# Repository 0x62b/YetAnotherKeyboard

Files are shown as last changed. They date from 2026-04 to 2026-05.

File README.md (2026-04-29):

# YetAnotherKeyboard
This is an 65% mechanical keyboard with hot-swappable MX style switches. The design is based on a nice!nano microcontroller and a nice!view display.
It also supports wireless operation with a standard lithium polymer battery. The nano also supports a USB connection.

## Repo structure
- CAD files including the individual parts and full assembly can be found in `cad/`
- The KiCad PCB design files can be found in `PCB/`
- Production gerbers can be found in `PCB/production`
- Firmware can be found in `firmware/`

## BOM
Total cost: 55.39 USD\
Parts can all be sourced from AliExpress.

## PCB
Parameters:
* 2 layer
* Material: FR-4
* Either HASL (leaded is much cheaper)
* White solder mask

Dimensions: 98.21mm*329.75mm\
PCB cost: 17 USD\
Shipping cost: 12.83 USD\
Total cost: 29.83 USD

## Case
Material: PLA, PETG, anything is fine really\
Nozzle: 0.4mm/0.6mm/0.8mm\
The case is far too big to fit on a standard 256mm^3 bed. If you want to replicate this build (for some reason) you may need to split the case. However I have access to a Prusa XL so I will use that.

## Firmware
ZMK, firmware is located in a submodule, https://github.com/0x62b/YetAnotherKeyboard-config

## Cost
Parts: 55.39 USD\
PCB: 29.83 USD\
Grand total: 85.22 USD (approx because of conversion rates)

## Images


There's probably a more efficient way to do matrix but...




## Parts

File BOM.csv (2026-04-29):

Name | Quantity | Unit price (AUD) | Extended Price (AUD) | Extended Price(USD) | Notes | Link
Pro Micro NRF52840 | 1 | 5.83 | 5.83 | 4.18 | nice!nano footprint is Pro Micro compatible | https://www.aliexpress.com/item/1005007266112508.html
nice!view | 1 | 19.59 | 19.59 | 14.02 | its probably some aliexpress knockoff but if it works it works (and if it doesnt i return it) | https://www.aliexpress.com/item/1005011620429396.html
1N4148 SOD-123 | 66 | 0.0284 | 2.84 | 2.04 | 100 pack | https://www.aliexpress.com/item/1005006323468521.html
0402 1K resistor | 1 | 0 | 0 | 0 | Owned | N/A
SPST push button | 1 | 0.039 | 1.94 | 1.39 | 50 pack | https://www.aliexpress.com/item/1005005279088080.html
MX switches | 66 | 0.42 | 29.39 | 21.10 | 70 pack | https://www.aliexpress.com/item/1005007983672026.html
Keycaps set | 1 | 0 | 0 | 0 | Owned | https://www.aliexpress.com/item/1005009162201589.html
Stabilisers | 1 | 3.99 | 3.99 | 2.86 | N/A | https://www.aliexpress.com/item/1005007212869086.html
Battery | 1 | 0 | 0 | 0 | Owned | https://core-electronics.com.au/lipo-polymer-lithium-ion-battery-120mah.html
Hotswap sockets | 1 | 12.29 | 12.29 | 8.8 | 100 pack | https://www.aliexpress.com/item/1005006105603269.html

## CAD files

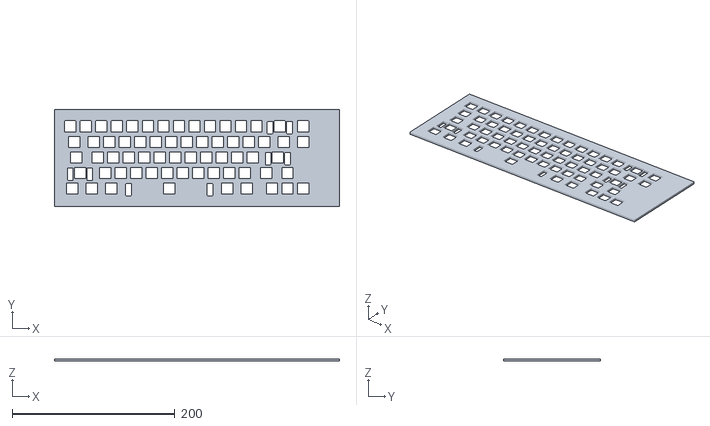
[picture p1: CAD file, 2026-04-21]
cad/top case.stl
350.1 x 118.6 x 3.00

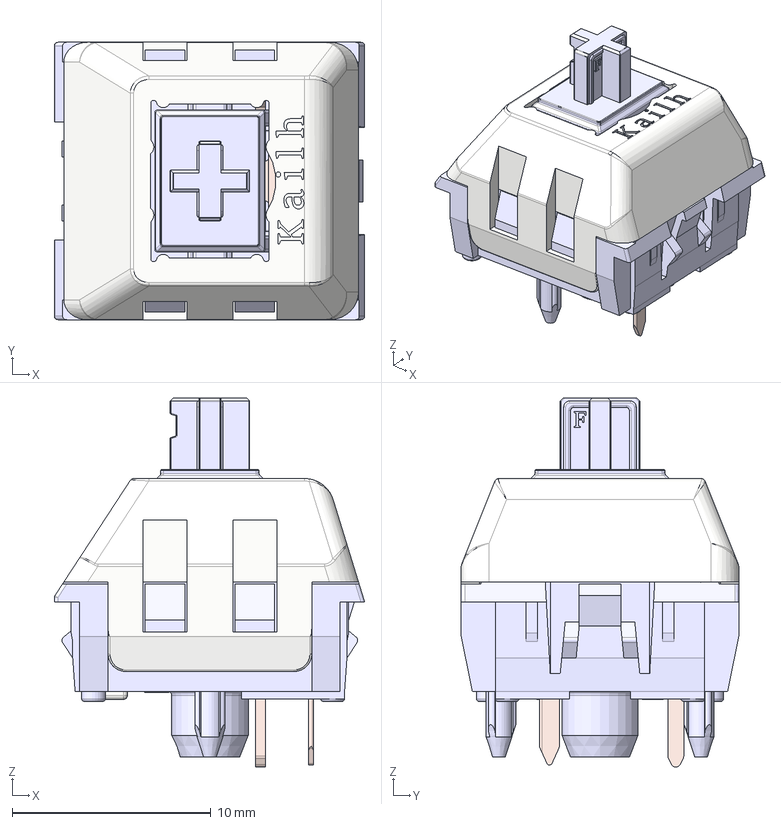
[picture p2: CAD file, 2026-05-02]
PCB/models/Kailh Polia.step
15.6 x 14.0 x 18.5 mm
Housing
ThickContact
SpringContact
Stem
Lid

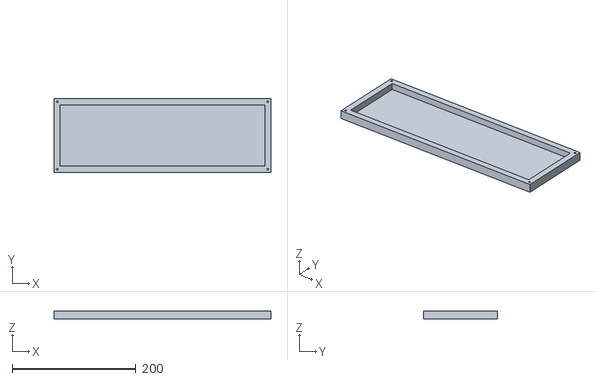
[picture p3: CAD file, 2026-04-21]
cad/bottom case.stl
350.1 x 118.6 x 13.0

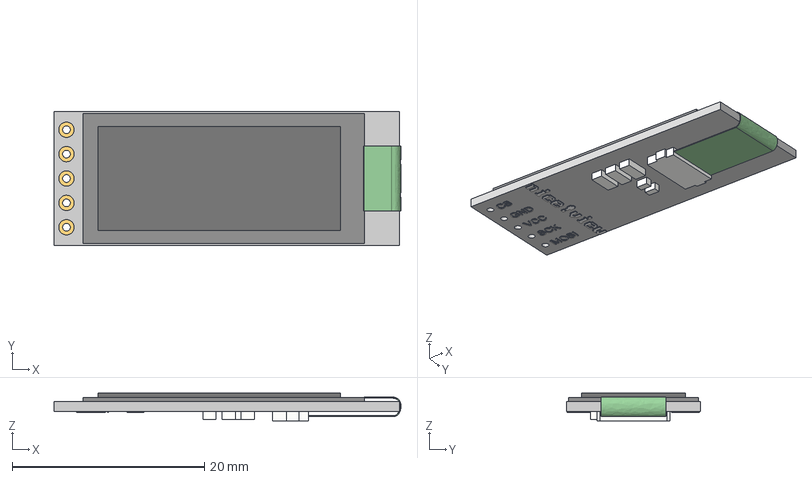
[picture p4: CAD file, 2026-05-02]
PCB/models/nice!view.step
36.1 x 14.0 x 2.90 mm

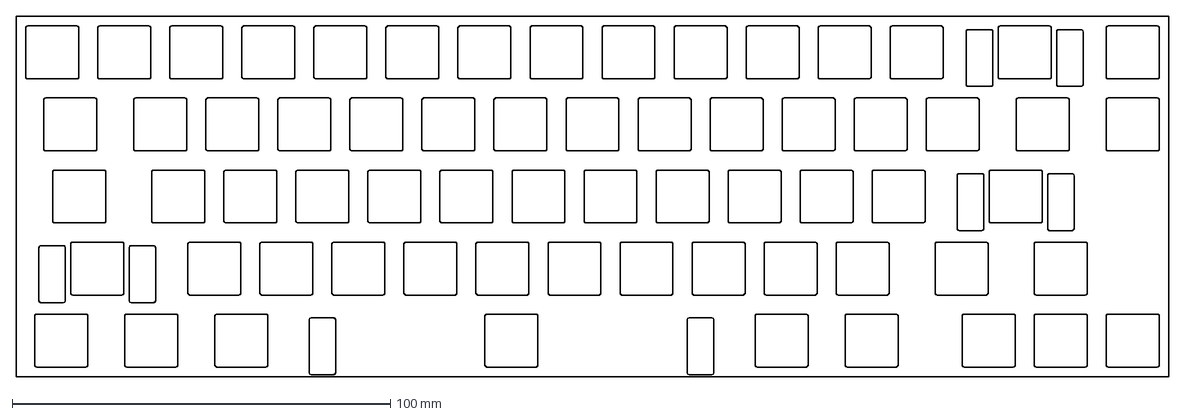
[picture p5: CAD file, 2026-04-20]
cad/plate-2026-04-20T23_23_47.740Z.dxf
304.8 x 95.2 mm

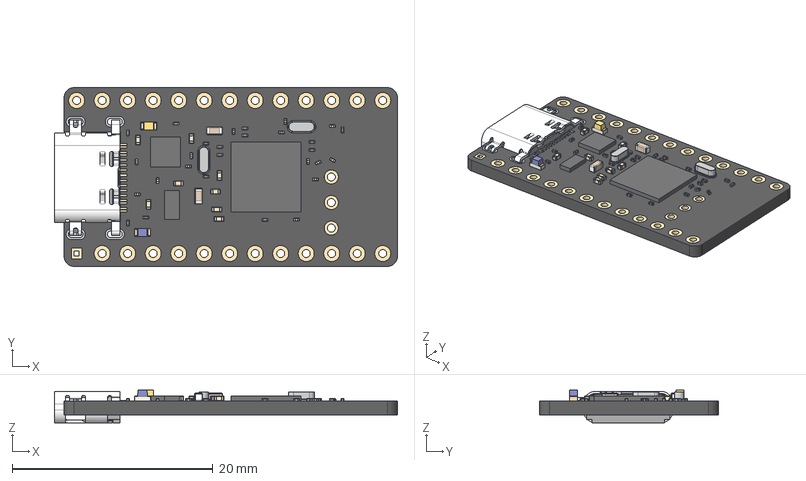
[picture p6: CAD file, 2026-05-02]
PCB/models/nice!nano v2.step
34.2 x 17.8 x 3.28 mm
nice!nano v1.0
SSOP16
LED_0603_1608Metric_ON
LED_0603_1608Metric_ON_1
Crystal Oscillator
Crystal Oscillator_1
usb4520-03-0-a_1
C0201 x 21
C0402 x 8
C0201_1 x 7

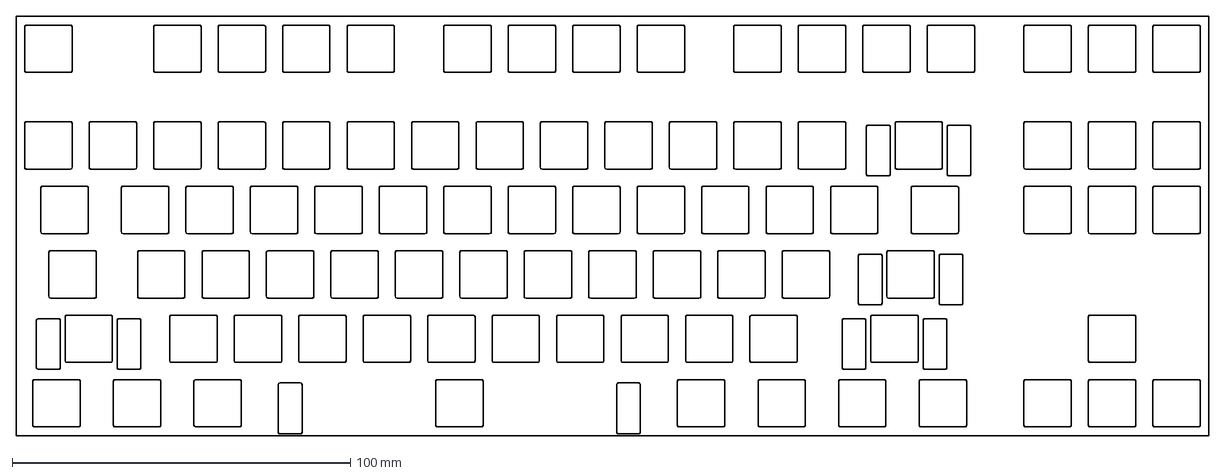
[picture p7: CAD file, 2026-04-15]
cad/plate-2026-04-14T12_41_01.630Z.dxf
352.4 x 123.8 mm

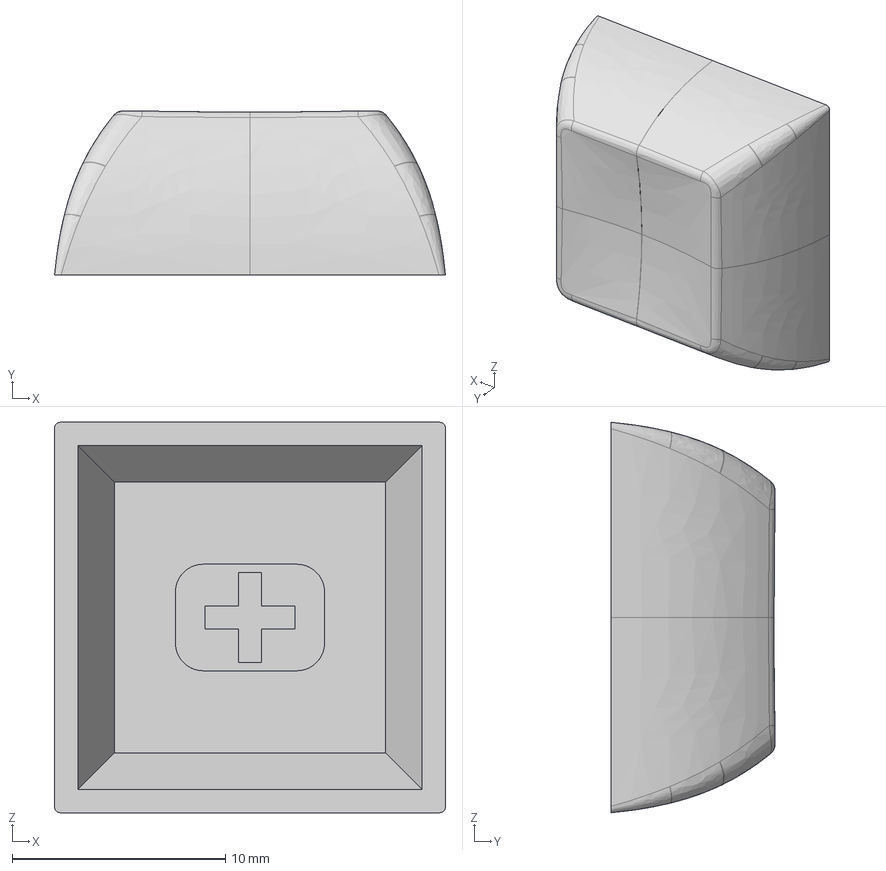
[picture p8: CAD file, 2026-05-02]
PCB/models/DSA_Keycap_CherryMX.step
18.3 x 7.69 x 18.3 mm

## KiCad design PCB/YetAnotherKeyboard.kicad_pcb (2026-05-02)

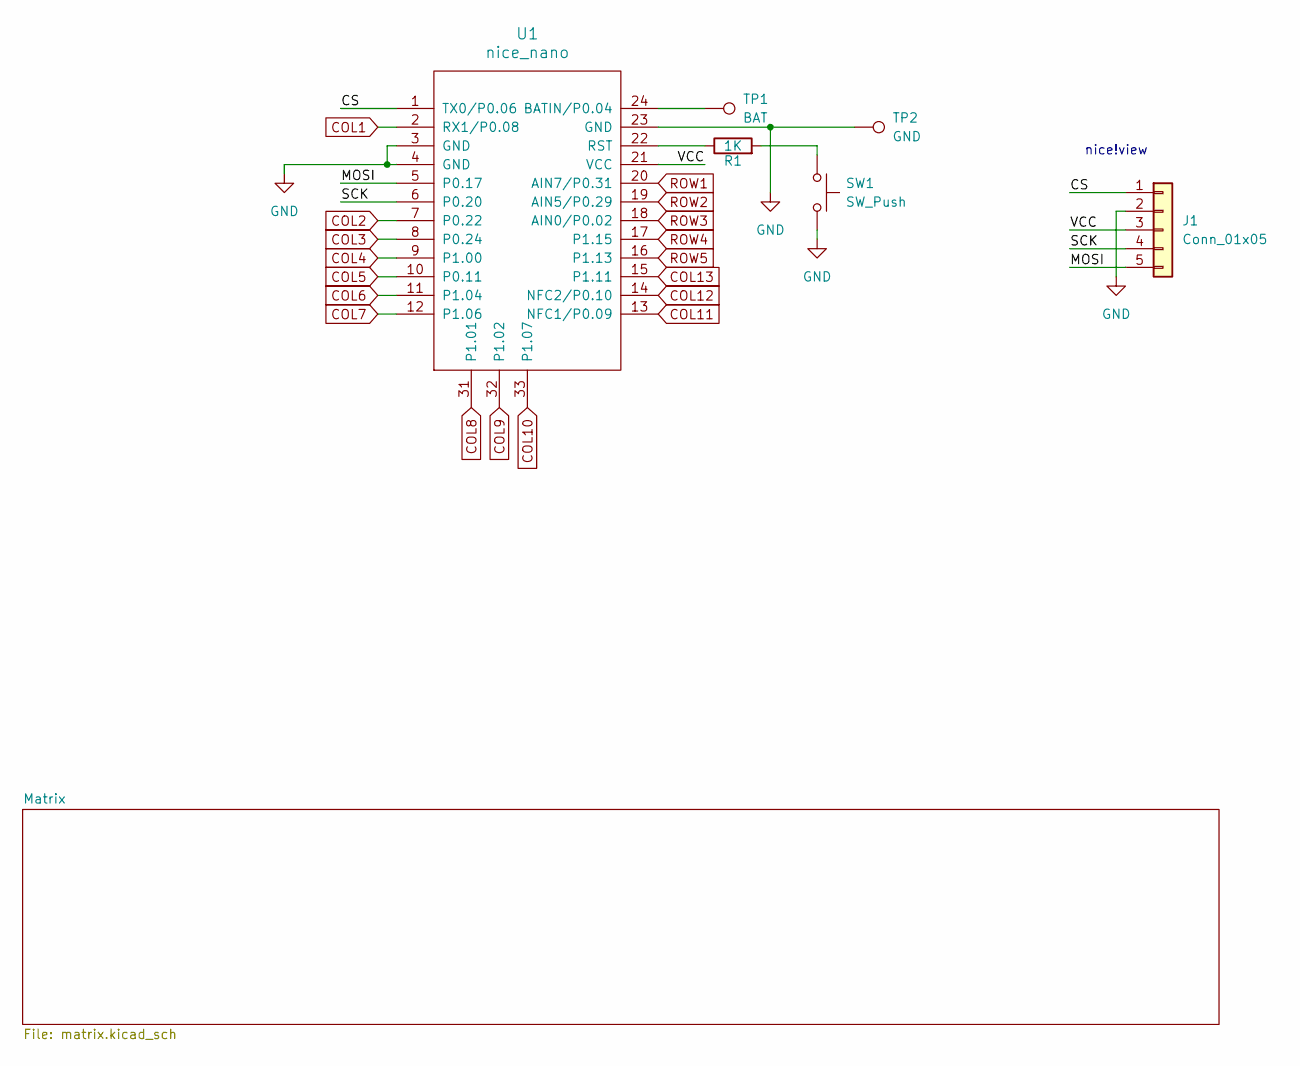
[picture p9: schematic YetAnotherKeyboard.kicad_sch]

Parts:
J1: Conn_01x05; PinHeader_1x05_P2.54mm_Vertical
R1: 1K; R_0402_1005Metric
SW1: SW_Push; SW_Push_SPST_NO_Alps_SKRK
TP1: BAT; TestPoint_Pad_D2.0mm
TP2: GND; TestPoint_Pad_D2.0mm
U1: nice_nano

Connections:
/CS: J1.1, U1.1 (TX0/P0.06)
/MOSI: J1.5, U1.5 (P0.17)
/SCK: J1.4, U1.6 (P0.20)
/VCC: J1.3, U1.21 (VCC)
COL1: U1.2 (RX1/P0.08); also elsewhere on the board
COL2: U1.7 (P0.22); also elsewhere on the board
COL3: U1.8 (P0.24); also elsewhere on the board
COL4: U1.9 (P1.00); also elsewhere on the board
COL5: U1.10 (P0.11); also elsewhere on the board
COL6: U1.11 (P1.04); also elsewhere on the board
COL7: U1.12 (P1.06); also elsewhere on the board
COL8: U1.31 (P1.01); also elsewhere on the board
COL9: U1.32 (P1.02); also elsewhere on the board
COL10: U1.33 (P1.07); also elsewhere on the board
COL11: U1.13 (NFC1/P0.09); also elsewhere on the board
COL12: U1.14 (NFC2/P0.10); also elsewhere on the board
COL13: U1.15 (P1.11); also elsewhere on the board
GND: J1.2, SW1.2, TP2.1 (1_1), U1.3 (GND), U1.4 (GND), U1.23 (GND)
unnamed: R1.2, SW1.1
unnamed: TP1.1 (1_1), U1.24 (BATIN/P0.04)
unnamed: R1.1, U1.22 (RST)
ROW1: U1.20 (AIN7/P0.31); also elsewhere on the board
ROW2: U1.19 (AIN5/P0.29); also elsewhere on the board
ROW3: U1.18 (AIN0/P0.02); also elsewhere on the board
ROW4: U1.17 (P1.15); also elsewhere on the board
ROW5: U1.16 (P1.13); also elsewhere on the board

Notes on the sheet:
nice!view

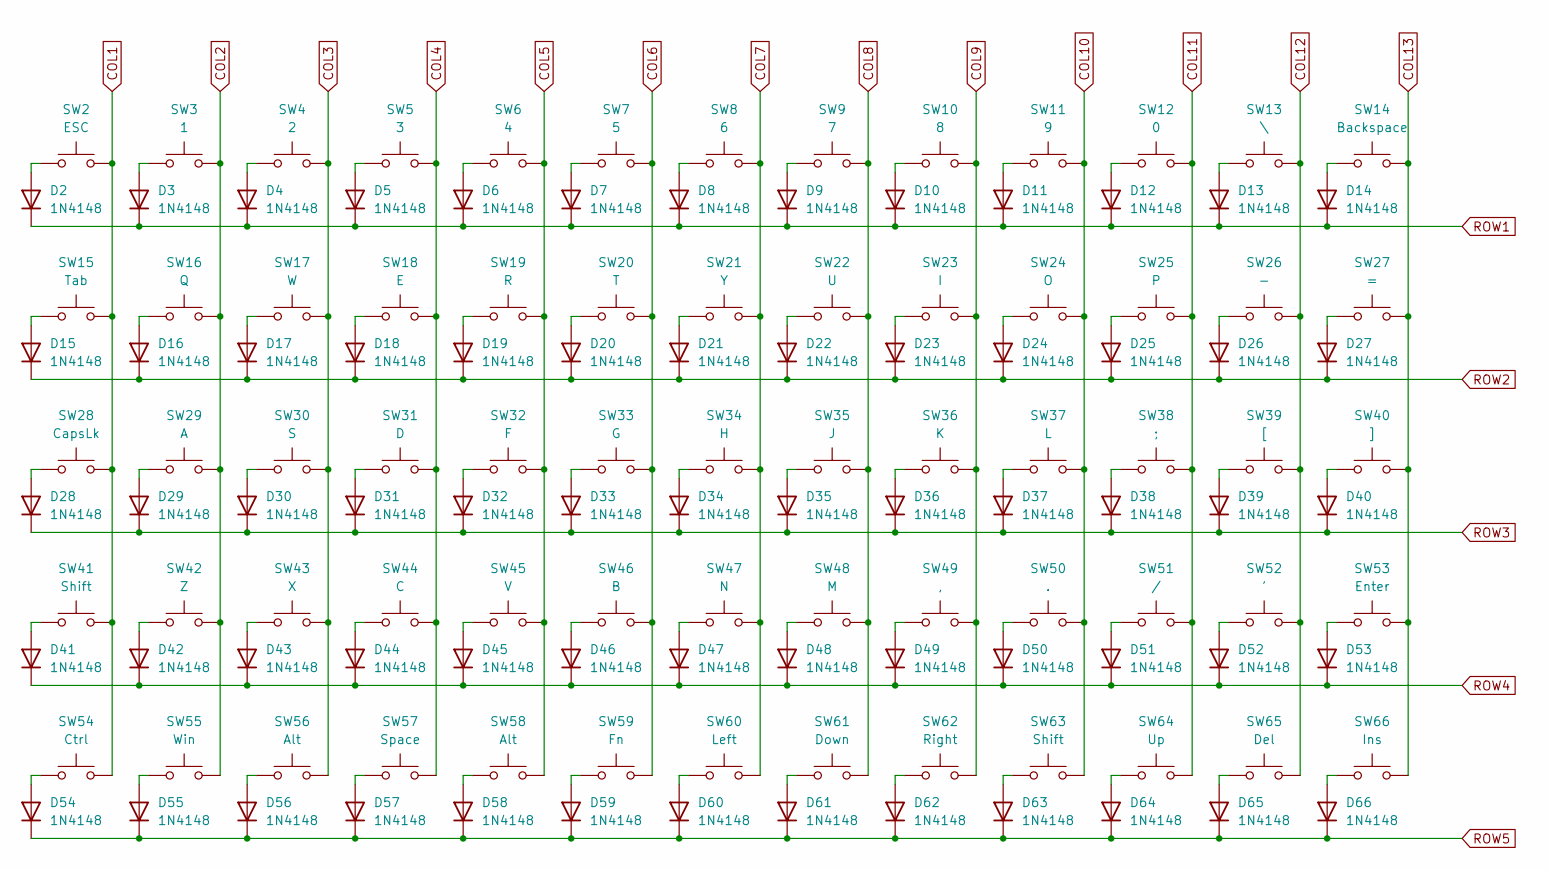
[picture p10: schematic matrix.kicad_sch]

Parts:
D2, D3, D4, D5, D6, D7, D8, D9, D10, D11, D12, D13, D14, D15, D16, D17, D18, D19, D20, D21, D22, D23, D24, D25, D26, D27, D28, D29, D30, D31, D32, D33, D34, D35, D36, D37, D38, D39, D40, D41, D42, D43, D44, D45, D46, D47, D48, D49, D50, D51, D52, D53, D54, D55, D56, D57, D58, D59, D60, D61, D62, D63, D64, D65, D66: 1N4148; D_SOD-123
SW2: ESC; MX-Hotswap-1U
SW3: 1; MX-Hotswap-1U
SW4: 2; MX-Hotswap-1U
SW5: 3; MX-Hotswap-1U
SW6: 4; MX-Hotswap-1U
SW7: 5; MX-Hotswap-1U
SW8: 6; MX-Hotswap-1U
SW9: 7; MX-Hotswap-1U
SW10: 8; MX-Hotswap-1U
SW11: 9; MX-Hotswap-1U
SW12: 0; MX-Hotswap-1U
SW13: \; MX-Hotswap-1.5U
SW14: Backspace; MX-Hotswap-2U
SW15: Tab; MX-Hotswap-1.5U
SW16: Q; MX-Hotswap-1U
SW17: W; MX-Hotswap-1U
SW18: E; MX-Hotswap-1U
SW19: R; MX-Hotswap-1U
SW20: T; MX-Hotswap-1U
SW21: Y; MX-Hotswap-1U
SW22: U; MX-Hotswap-1U
SW23: I; MX-Hotswap-1U
SW24: O; MX-Hotswap-1U
SW25: P; MX-Hotswap-1U
SW26: -; MX-Hotswap-1U
SW27: =; MX-Hotswap-1U
SW28: CapsLk; MX-Hotswap-1.75U
SW29: A; MX-Hotswap-1U
SW30: S; MX-Hotswap-1U
SW31: D; MX-Hotswap-1U
SW32: F; MX-Hotswap-1U
SW33: G; MX-Hotswap-1U
SW34: H; MX-Hotswap-1U
SW35: J; MX-Hotswap-1U
SW36: K; MX-Hotswap-1U
SW37: L; MX-Hotswap-1U
SW38: ;; MX-Hotswap-1U
SW39: [; MX-Hotswap-1U
SW40: ]; MX-Hotswap-1U
SW41: Shift; MX-Hotswap-2.25U
SW42: Z; MX-Hotswap-1U
SW43: X; MX-Hotswap-1U
SW44: C; MX-Hotswap-1U
SW45: V; MX-Hotswap-1U
SW46: B; MX-Hotswap-1U
SW47: N; MX-Hotswap-1U
SW48: M; MX-Hotswap-1U
SW49: ,; MX-Hotswap-1U
SW50: .; MX-Hotswap-1U
SW51: /; MX-Hotswap-1U
SW52: '; MX-Hotswap-1U
SW53: Enter; MX-Hotswap-2.25U
SW54: Ctrl; MX-Hotswap-1.25U
SW55: Win; MX-Hotswap-1.25U
SW56, SW58: Alt; MX-Hotswap-1.25U
SW57: Space; MX-Hotswap-6.25U
SW59: Fn; MX-Hotswap-1.25U
SW60: Left; MX-Hotswap-1U
SW61: Down; MX-Hotswap-1U
SW62: Right; MX-Hotswap-1U
SW63: Shift; MX-Hotswap-1.75U
SW64: Up; MX-Hotswap-1U
SW65: Del; MX-Hotswap-1U
SW66: Ins; MX-Hotswap-1U

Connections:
COL1: SW2.2, SW15.2, SW28.2, SW41.2, SW54.2; also elsewhere on the board
COL2: SW3.2, SW16.2, SW29.2, SW42.2, SW55.2; also elsewhere on the board
COL3: SW4.2, SW17.2, SW30.2, SW43.2, SW56.2; also elsewhere on the board
COL4: SW5.2, SW18.2, SW31.2, SW44.2, SW57.2; also elsewhere on the board
COL5: SW6.2, SW19.2, SW32.2, SW45.2, SW58.2; also elsewhere on the board
COL6: SW7.2, SW20.2, SW33.2, SW46.2, SW59.2; also elsewhere on the board
COL7: SW8.2, SW21.2, SW34.2, SW47.2, SW60.2; also elsewhere on the board
COL8: SW9.2, SW22.2, SW35.2, SW48.2, SW61.2; also elsewhere on the board
COL9: SW10.2, SW23.2, SW36.2, SW49.2, SW62.2; also elsewhere on the board
COL10: SW11.2, SW24.2, SW37.2, SW50.2, SW63.2; also elsewhere on the board
COL11: SW12.2, SW25.2, SW38.2, SW51.2, SW64.2; also elsewhere on the board
COL12: SW13.2, SW26.2, SW39.2, SW52.2, SW65.2; also elsewhere on the board
COL13: SW14.2, SW27.2, SW40.2, SW53.2, SW66.2; also elsewhere on the board
unnamed: D2.2 (A), SW2.1
unnamed: D3.2 (A), SW3.1
unnamed: D4.2 (A), SW4.1
unnamed: D5.2 (A), SW5.1
unnamed: D6.2 (A), SW6.1
unnamed: D7.2 (A), SW7.1
unnamed: D8.2 (A), SW8.1
unnamed: D9.2 (A), SW9.1
unnamed: D10.2 (A), SW10.1
unnamed: D11.2 (A), SW11.1
unnamed: D12.2 (A), SW12.1
unnamed: D13.2 (A), SW13.1
unnamed: D14.2 (A), SW14.1
unnamed: D15.2 (A), SW15.1
unnamed: D16.2 (A), SW16.1
unnamed: D17.2 (A), SW17.1
unnamed: D18.2 (A), SW18.1
unnamed: D19.2 (A), SW19.1
unnamed: D20.2 (A), SW20.1
unnamed: D21.2 (A), SW21.1
unnamed: D22.2 (A), SW22.1
unnamed: D23.2 (A), SW23.1
unnamed: D24.2 (A), SW24.1
unnamed: D25.2 (A), SW25.1
unnamed: D26.2 (A), SW26.1
unnamed: D27.2 (A), SW27.1
unnamed: D28.2 (A), SW28.1
unnamed: D29.2 (A), SW29.1
unnamed: D30.2 (A), SW30.1
unnamed: D31.2 (A), SW31.1
unnamed: D32.2 (A), SW32.1
unnamed: D33.2 (A), SW33.1
unnamed: D34.2 (A), SW34.1
unnamed: D35.2 (A), SW35.1
unnamed: D36.2 (A), SW36.1
unnamed: D37.2 (A), SW37.1
unnamed: D38.2 (A), SW38.1
unnamed: D39.2 (A), SW39.1
unnamed: D40.2 (A), SW40.1
unnamed: D41.2 (A), SW41.1
unnamed: D42.2 (A), SW42.1
unnamed: D43.2 (A), SW43.1
unnamed: D44.2 (A), SW44.1
unnamed: D45.2 (A), SW45.1
unnamed: D46.2 (A), SW46.1
unnamed: D47.2 (A), SW47.1
unnamed: D48.2 (A), SW48.1
unnamed: D49.2 (A), SW49.1
unnamed: D50.2 (A), SW50.1
unnamed: D51.2 (A), SW51.1
unnamed: D52.2 (A), SW52.1
unnamed: D53.2 (A), SW53.1
unnamed: D54.2 (A), SW54.1
unnamed: D55.2 (A), SW55.1
unnamed: D56.2 (A), SW56.1
unnamed: D57.2 (A), SW57.1
unnamed: D58.2 (A), SW58.1
unnamed: D59.2 (A), SW59.1
unnamed: D60.2 (A), SW60.1
unnamed: D61.2 (A), SW61.1
unnamed: D62.2 (A), SW62.1
unnamed: D63.2 (A), SW63.1
unnamed: D64.2 (A), SW64.1
unnamed: D65.2 (A), SW65.1
unnamed: D66.2 (A), SW66.1
ROW1: D2.1 (K), D3.1 (K), D4.1 (K), D5.1 (K), D6.1 (K), D7.1 (K), D8.1 (K), D9.1 (K), D10.1 (K), D11.1 (K), D12.1 (K), D13.1 (K), D14.1 (K); also elsewhere on the board
ROW2: D15.1 (K), D16.1 (K), D17.1 (K), D18.1 (K), D19.1 (K), D20.1 (K), D21.1 (K), D22.1 (K), D23.1 (K), D24.1 (K), D25.1 (K), D26.1 (K), D27.1 (K); also elsewhere on the board
ROW3: D28.1 (K), D29.1 (K), D30.1 (K), D31.1 (K), D32.1 (K), D33.1 (K), D34.1 (K), D35.1 (K), D36.1 (K), D37.1 (K), D38.1 (K), D39.1 (K), D40.1 (K); also elsewhere on the board
ROW4: D41.1 (K), D42.1 (K), D43.1 (K), D44.1 (K), D45.1 (K), D46.1 (K), D47.1 (K), D48.1 (K), D49.1 (K), D50.1 (K), D51.1 (K), D52.1 (K), D53.1 (K); also elsewhere on the board
ROW5: D54.1 (K), D55.1 (K), D56.1 (K), D57.1 (K), D58.1 (K), D59.1 (K), D60.1 (K), D61.1 (K), D62.1 (K), D63.1 (K), D64.1 (K), D65.1 (K), D66.1 (K); also elsewhere on the board

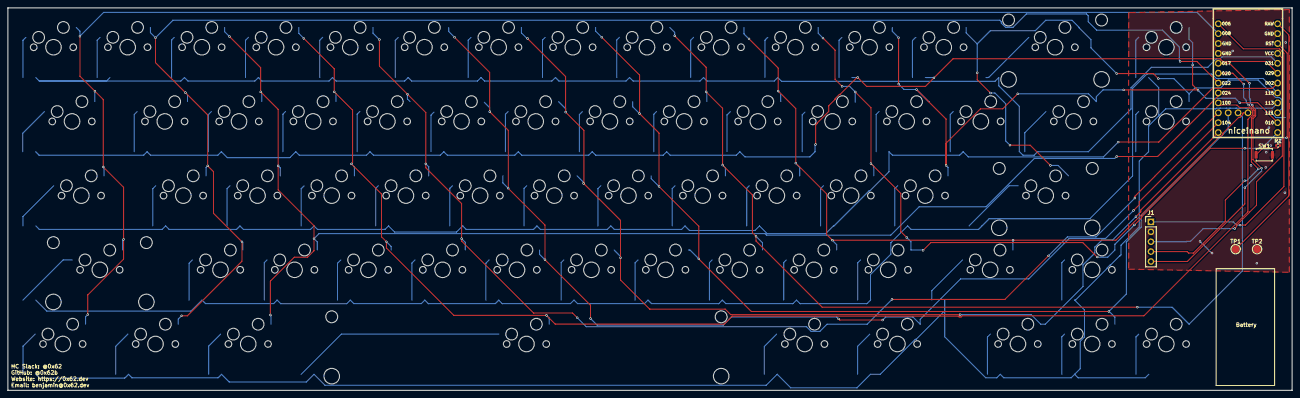
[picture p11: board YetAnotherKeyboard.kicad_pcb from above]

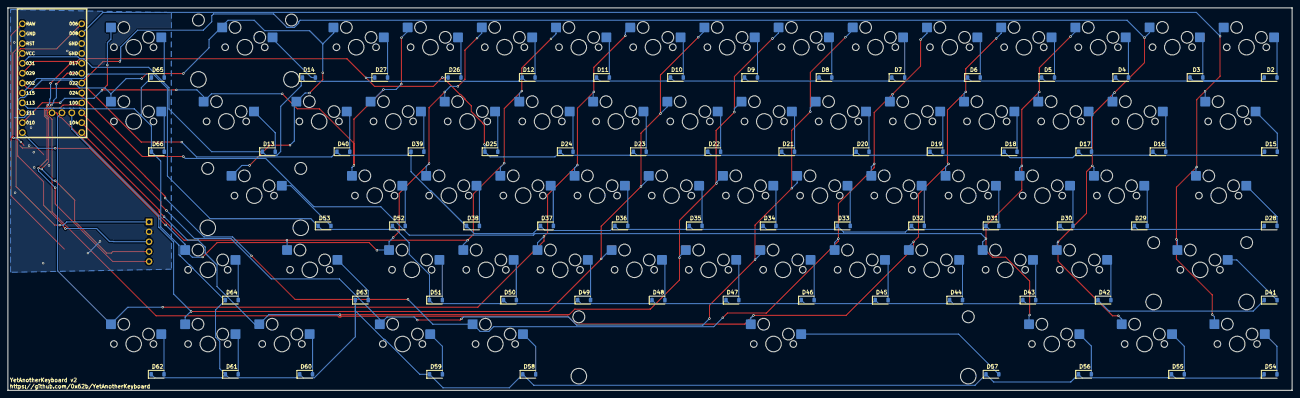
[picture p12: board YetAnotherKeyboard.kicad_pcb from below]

Board: 2 copper layers, 329.7 x 98.2 mm, 136 parts (130 on the bottom side), 91 nets.

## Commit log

2026-04-13 rev 1.1
    [YetAnotherKeyboard.kicad_pcb, YetAnotherKeyboard.kicad_sch, matrix.kicad_sch]
2026-04-14 production files, repo structure
    [YetAnotherKeyboard-B_Cu.gbr, YetAnotherKeyboard-B_Mask.gbr, YetAnotherKeyboard-B_Paste.gbr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]
2026-04-15 add dxf plate template
    [plate-2026-04-14T12_41_01.630Z.dxf]
2026-04-15 fix footprints/adjust bom
    [BOM.csv, YetAnotherKeyboard.kicad_pcb]
2026-04-15 idt you CAN get a .4 resistor lmao
    [BOM.csv]
2026-04-15 board + case files
    [board.step, case.step]
2026-04-15 update bom to reflect actual prices
    [BOM.csv]
2026-04-15 add keycaps to bom
    [BOM.csv]
2026-04-15 add stabs to bom
    [BOM.csv]
2026-04-15 make the bom more complete :sparkles:
    [BOM.csv]
2026-04-16 change schema to nice! compenents
    [YetAnotherKeyboard.kicad_sch, matrix.kicad_sch]
2026-04-20 65% pcb
    [YetAnotherKeyboard.kicad_pcb, YetAnotherKeyboard.kicad_sch, matrix.kicad_sch]
2026-04-20 new production files
    [YetAnotherKeyboard-B_Cu.gbr, YetAnotherKeyboard-B_Mask.gbr, YetAnotherKeyboard-B_Paste.gbr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]
2026-04-20 update bom for new pcb
    [BOM.csv]
2026-04-20 65% layout plate files
    [plate-2026-04-20T23_23_47.740Z.dxf]
2026-04-21 case stl files
    [board.step, bottom case.stl, case.step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]
2026-05-02 3d models
    [DSA_Keycap_CherryMX.step, Kailh Polia.step, YetAnotherKeyboard.kicad_pcb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]
2026-05-02 board render
